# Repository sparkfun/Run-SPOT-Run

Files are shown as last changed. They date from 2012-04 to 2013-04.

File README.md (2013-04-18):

SatUpLink Shield
================
[SatUpLink Shield  
*SatUpLink Shield(DEV-11088)*](https://www.sparkfun.com/products/11088)

Run SPOT Run is a breakout board for the SPOT Connect version of the SPOT Geolocator. It is now retired on the SparkFun store front.

You will need your own registered SPOT ($150 for the hardware, $100 for the subscription), but after that, you should be able to broadcast small text messages (up to 40 characters) from most land masses on the globe.

Please see this [tutorial](http://www.sparkfun.com/tutorials/340) for more information. 

The hardware files were designed in Eagle v6.1.0 , and the firmware was developed in Arduino v1.0.

Repository Contents
-------------------
* **/Firmware** - Example Arduino sketch for running the shield 
* **/Hardware** - All Eagle design files (.brd, .sch)

License Information
-------------------
The hardware is released under [Creative Commons Share-alike 3.0](http://creativecommons.org/licenses/by-sa/3.0/).  
All other code is open source so please feel free to do anything you want with it; you buy me a beer if you use this and we meet someday ([Beerware license](http://en.wikipedia.org/wiki/Beerware)).

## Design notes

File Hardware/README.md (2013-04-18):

# What Are these Files?

The .sch and .brd files hare are Eagle CAD schematic and PCB design files.

These files were created with Eagle 6.1.0, you'll need Eagle 6.0 or later to open them up. There is a free, lite, version of Eagle available from [cadsoftusa.com](cadsoftusa.com).

# License

This product is open source! These Eagle files are released under the Creative Commons Share-Alike Attribution license ([CC BY-SA 3.0](http://creativecommons.org/licenses/by-sa/3.0/us/)).

Please use, reuse, and modify these files as you see fit. Please maintain attribution and release anything derivative under the same license.

- Your friends at SparkFun.

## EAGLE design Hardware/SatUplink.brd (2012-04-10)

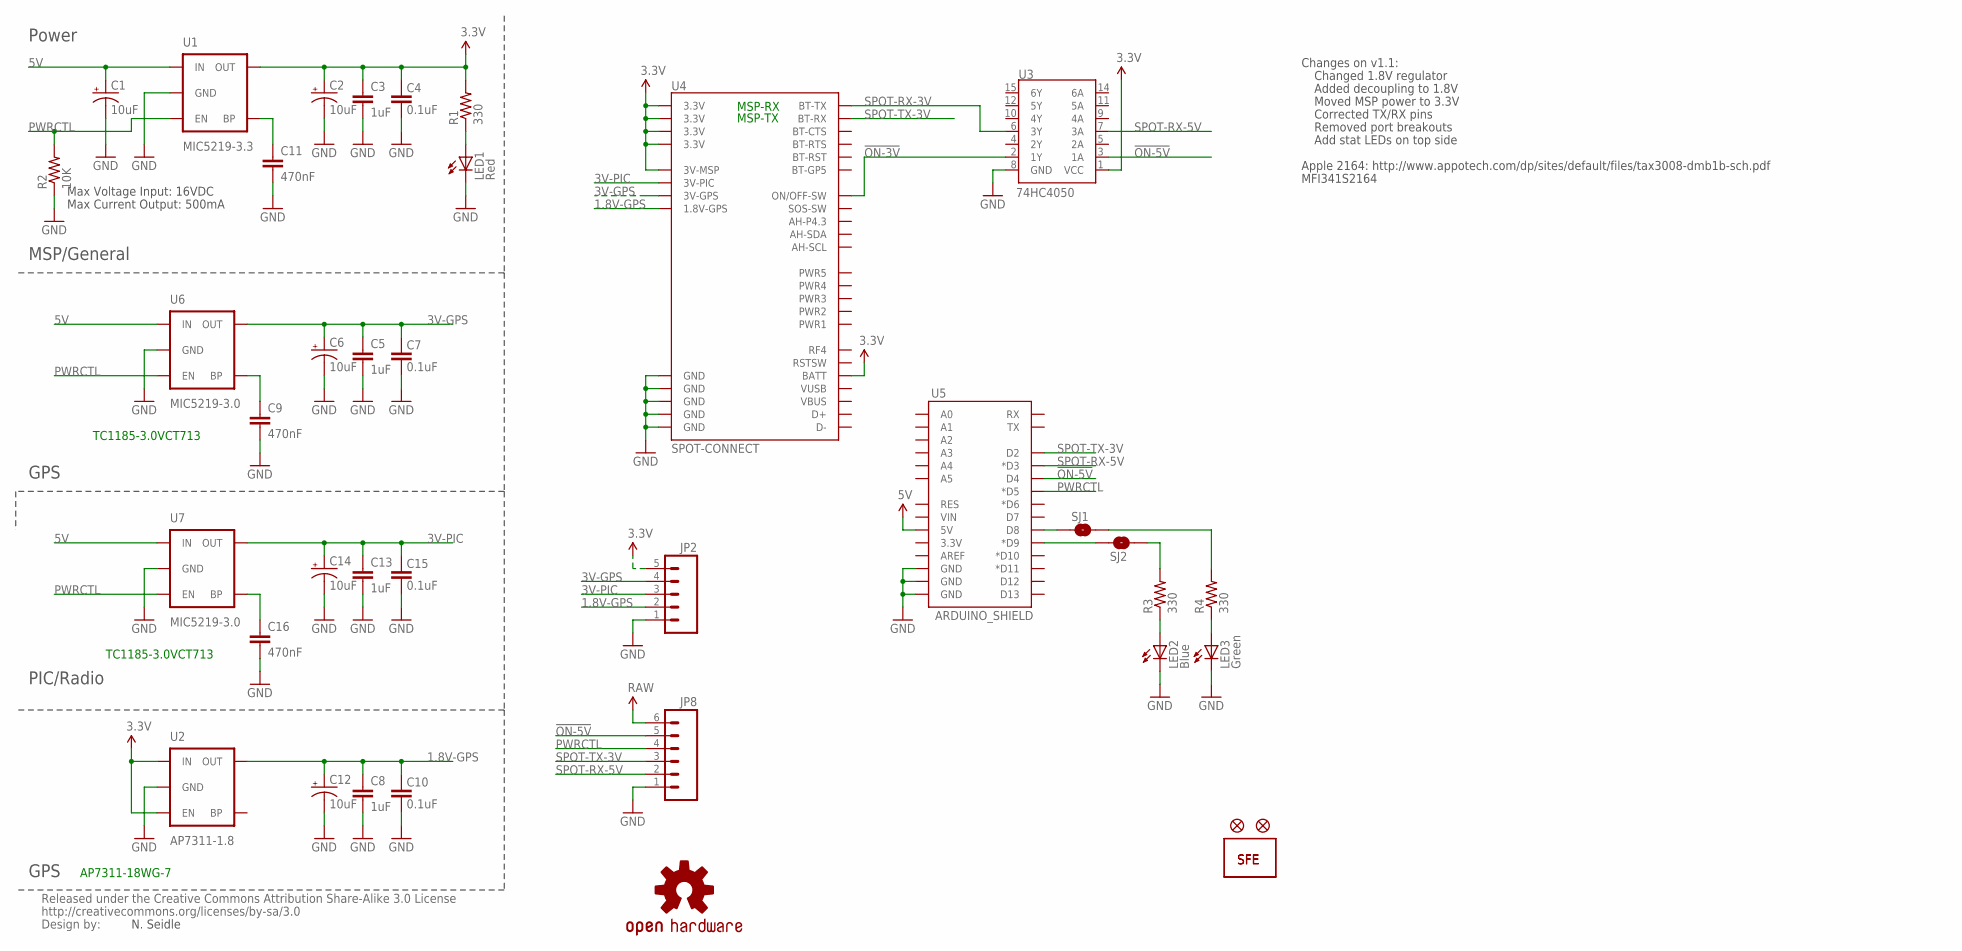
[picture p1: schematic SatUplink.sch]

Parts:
C1, C2, C6, C12, C14: 10uF; EIA3216
C3, C5, C8, C13: 1uF; 0402-CAP
C4, C7, C10, C15: 0.1uF; 0402-CAP
C9, C11, C16: 470nF; 0402-CAP
JP2: M05PTH; 1X05
JP8: M06SIP; 1X06
JP10, JP11: FIDUCIALUFIDUCIAL; MICRO-FIDUCIAL
LED1: Red; LED-0603
LED2: Blue; LED-0603
LED3: Green; LED-0603
R1, R3, R4: 330; 0402-RES
R2: 10K; 0402-RES
SJ1, SJ2: SOLDERJUMPERTRACE; SJ_2S-TRACE
U1: MIC5219-3.3; SOT23-5
U2: AP7311-1.8; SOT23-5
U3: 74HC4050; SO016
U4: SPOT-CONNECT
U5: ARDUINO_SHIELD; DUEMILANOVE_VIAS
U6, U7: MIC5219-3.0; SOT23-5
U$1: LOGO-SFESK; SFE-LOGO-FLAME
U$2: CREATIVE_COMMONS
U$3: OSHW-LOGOS; OSHW-LOGO-S
U$11: LOGO-SFENEW; SFE-NEW-WEBLOGO

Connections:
1.8V-GPS: C8.1, C10.2, C12.A (+), JP2.2, U2.5 (OUT), U4.1.8V-GPS
3.3V: C2.A (+), C3.1, C4.2, JP2.5, R1.2, U1.5 (OUT), U2.1 (IN), U2.3 (EN), U3.1 (VCC), U4.3.3V@1 (3.3V), U4.3.3V@2 (3.3V), U4.3.3V@3 (3.3V), U4.3.3V@4 (3.3V), U4.3VMSP (3V-MSP), U4.BATT
3V-GPS: C5.1, C6.A (+), C7.2, JP2.4, U4.3V-GPS, U6.5 (OUT)
3V-PIC: C13.1, C14.A (+), C15.2, JP2.3, U4.3VPIC (3V-PIC), U7.5 (OUT)
5V: C1.A (+), JP8.6, U1.1 (IN), U5.5V, U6.1 (IN), U7.1 (IN)
!ON-3V: U3.2 (1Y), U4.ON/OFF (ON/OFF-SW)
!ON-5V: JP8.5, U3.3 (1A), U5.D4
GND: C1.C (-), C2.C (-), C3.2, C4.1, C5.2, C6.C (-), C7.1, C8.2, C9.2, C10.1, C11.2, C12.C (-), C13.2, C14.C (-), C15.1, C16.2, JP2.1, JP8.1, LED1.C, LED2.C, LED3.C, R2.1, U1.2 (GND), U2.2 (GND), U3.8 (GND), U4.GND@1 (GND), U4.GND@2 (GND), U4.GND@3 (GND), U4.GND@4 (GND), U4.GND@5 (GND), U5.GND@0 (GND), U5.GND@1 (GND), U5.GND@2 (GND), U6.2 (GND), U7.2 (GND)
unnamed: C16.1, U7.4 (BP)
unnamed: R4.2, SJ1.2
unnamed: R3.2, SJ2.2
unnamed: C9.1, U6.4 (BP)
unnamed: LED2.A, R3.1
unnamed: LED3.A, R4.1
unnamed: SJ1.1, U5.D8
unnamed: SJ2.1, U5.D9 (*D9)
unnamed: C11.1, U1.4 (BP)
unnamed: LED1.A, R1.1
PWRCTL: JP8.4, R2.2, U1.3 (EN), U5.D5 (*D5), U6.3 (EN), U7.3 (EN)
SPOT-RX-3V: U3.6 (3Y), U4.BT-TX
SPOT-RX-5V: JP8.2, U3.7 (3A), U5.D3 (*D3)
SPOT-TX-3V: JP8.3, U4.BT-RX, U5.D2

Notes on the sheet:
Max Voltage Input: 16VDC
Max Current Output: 500mA
N. Seidle
TC1185-3.0VCT713
Add stat LEDs on top side
Apple 2164: http://www.appotech.com/dp/sites/default/files/tax3008-dmb1b-sch.pdf
MFI341S2164
MSP-TX
MSP-RX
AP7311-18WG-7
Changes on v1.1:
Added decoupling to 1.8V
Changed 1.8V regulator
Moved MSP power to 3.3V
Corrected TX/RX pins
Removed port breakouts
PIC/Radio
GPS
MSP/General
Power

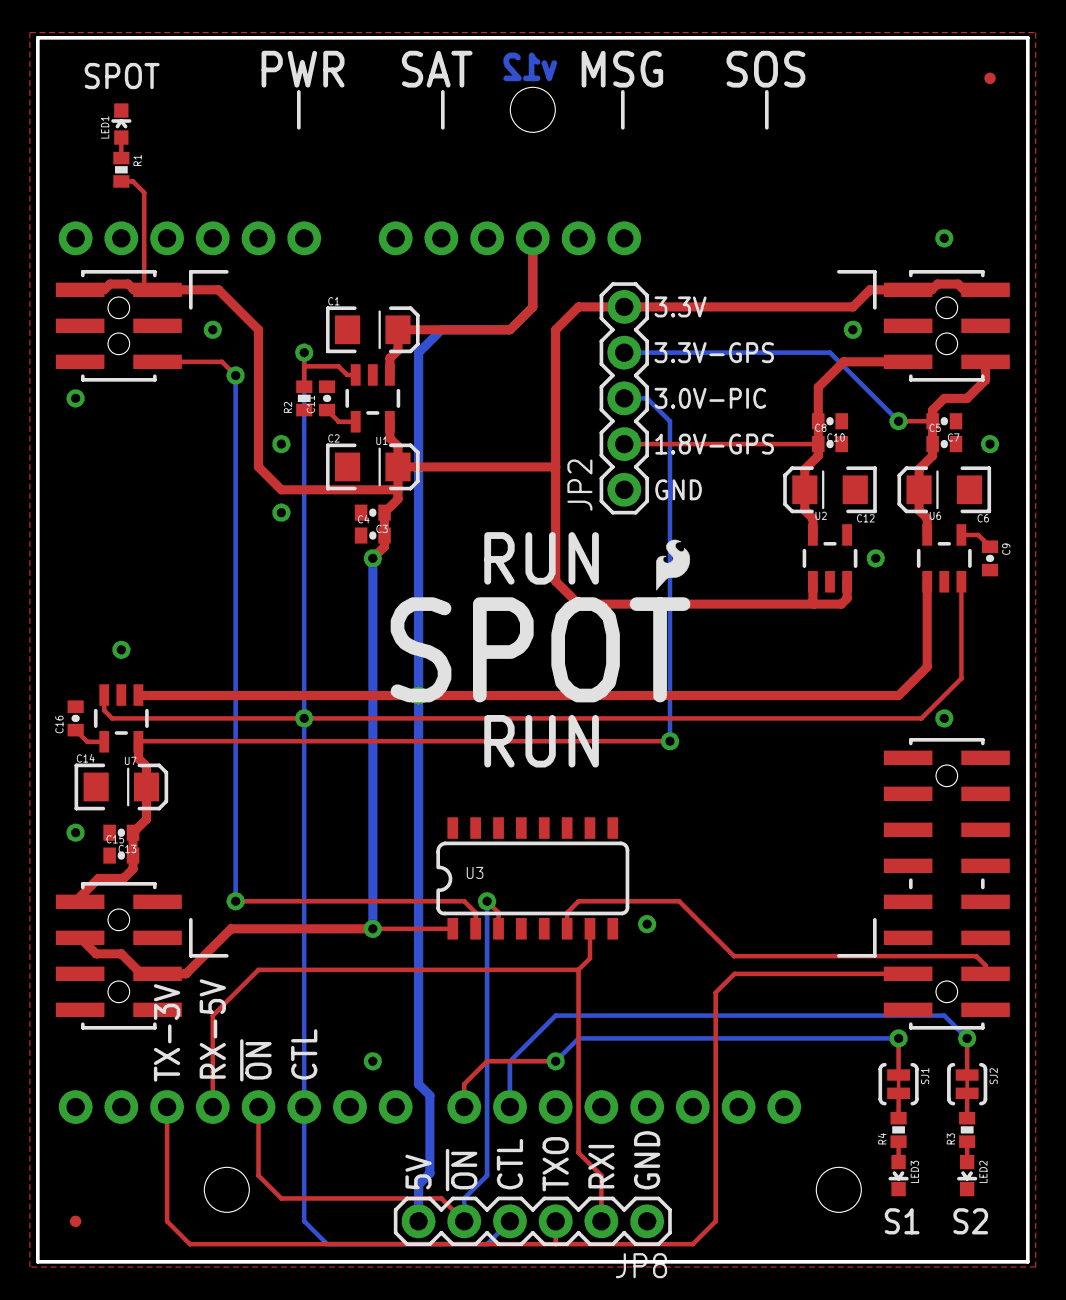
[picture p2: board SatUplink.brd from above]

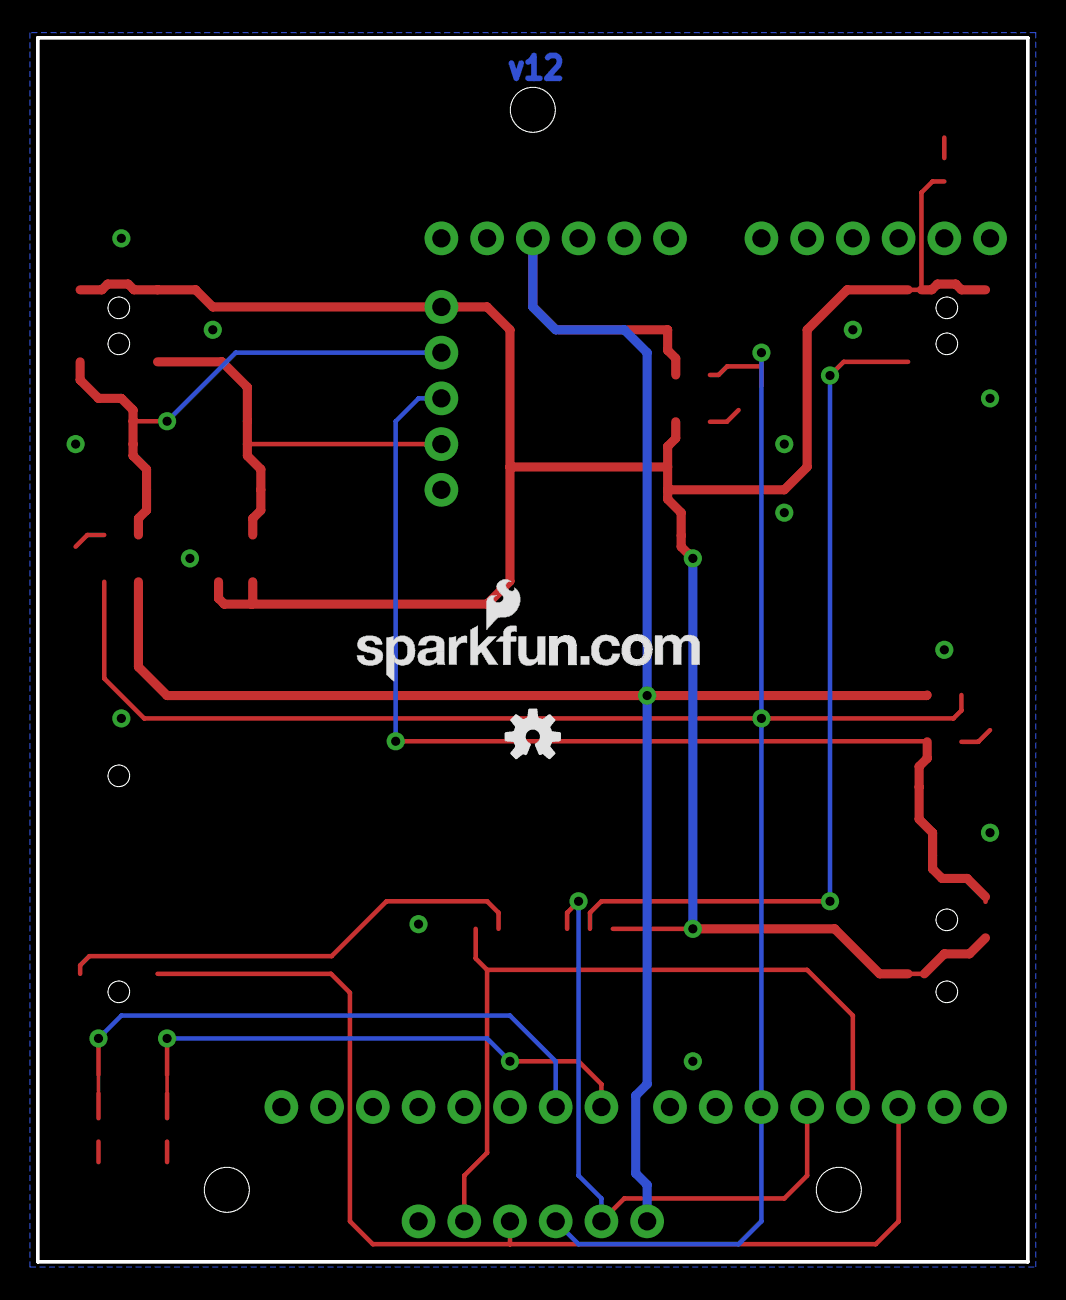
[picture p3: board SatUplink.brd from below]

Board: 2 copper layers, 55.0 x 68.0 mm, 40 parts (2 on the bottom side), 22 nets.

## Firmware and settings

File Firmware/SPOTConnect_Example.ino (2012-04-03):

/*
 12-22-2011
 Spark Fun Electronics 2012
 Nathan Seidle
 
 This code is public domain but you buy me a beer if you use this and we meet someday (Beerware license).
 
 This example code tells the SPOT to transmit the message "Hello Stars" and then check the unit's status registers.
 
 For more information, see the SparkFun tutorial: http://www.sparkfun.com/tutorials/340
 
 Log into the SPOT website and setup your SPOT to send text messages or emails to a known good recipient (I recommend
 your cell phone and your email). Remember to use an activated SPOT, outdoors with a clear view of the sky. 
 
 Connect the following pins
 SPOT TXO : Arduino 2
 SPOT RXI : Arduino 3
 SPOT CTL : Arduino 5
 SPOT ON* : Arduino 4

 Note: SoftwareSerial cannot handle incoming 115200bps so we had to bit-bang incoming bytes using getbyte_115200(). 
 SoftwareSerial opens pin 7 as the RX pin but we do not use it. Instead, the getbyte_115200 receives bytes on pin 3.
 getbyte_115200 is configured to work at 16Mz.
 */

#include <SoftwareSerial.h>

//All the following are variables needed to use SPOT
//-=-=-=-=-=-=-=-=-=-=-=-=-=-=-=-=-=-=-=-=-=-=-=-=-=-=-=-=-=-=-=-=-=-


int SPOTrx = 2; //Receive from SPOT (TXO pin on breakout) into pin 2 on Arduino
int SPOTtx = 3; //Transmit out to SPOT (RXI pin on breakout) from pin 3 on breakout
//SoftwareSerial(rxPin, txPin)
SoftwareSerial softSPOT(7, SPOTtx); //Dummy soft RX on 7 (not actually used), Soft TX out on SPOTtx

int onButton = 4; //Holding this pin low for more than 5 seconds will power up SPOT in Bluetooth discovery mode
int powerControl = 5; //This controls the voltage regulators on the SPOT breakout board, active high

int numberOfPowerOns = 0;
int unitStatus = 0; //0x00 = GPS/Radio powered off, 0x07 = GPS searching, 0x0F = GPS lock, 0x06 = transmitting to satellite network
int timeToNextCheckin = 0; //Starts at 0. In seconds Once GPS locks, will increase to a large number then count down to next try.
int sentTries = 0; //Starts at 0 and goes to 1, then to 2, then unit shuts down.
int gpsStatus = 0; //Goes to 0x01 once we have good GPS coords. GPS will then be powered down.
int satsInView = 0;

unsigned char SPOT_requestUnitID[] = { 
  0xAA, 0x03, 0x01 };

unsigned char SPOT_requestStatus[] = { 
  0xAA, 0x03, 0x52 };

unsigned char SPOT_requestLastGPS[] = { 
  0xAA, 0x03, 0x25 };

char buffer[200]; //Used for status sprintf things

int messageNumber = 1; //Let's add a # variable to the message we send out
//-=-=-=-=-=-=-=-=-=-=-=-=-=-=-=-=-=-=-=-=-=-=-=-=-=-=-=-=-=-=-=-=-=-

int statusLED = 13; //Arduino default stat LED

void setup() {
  Serial.begin(115200);

  pinMode(statusLED, OUTPUT);
  digitalWrite(statusLED, HIGH);

  int tries;
  for(tries = 0 ; tries < 3 ; tries++){

    SPOTsetup(); //Init the IO pins for the SPOT
    SPOTcheckStatus(); //Check for a valid response

    if(unitStatus != 255) break; //255 = SPOT didn't respond

    Serial.print("SPOT failed to respond.");
  }

  if(tries == 3) { //Give up!
    Serial.print("Please check connections.");
    
    while(1){ //Infini-blink error
      digitalWrite(8, HIGH);
      delay(1000);
      digitalWrite(8, LOW);
      delay(1000);
    }
  }
  
}

void loop() {
  
  if(SPOTcheckStatus()) {

    Serial.print("[Unit Status:");
    if(unitStatus == 0) Serial.print("Waiting Cmd]");
    else if(unitStatus == 0x07) Serial.print("GPS Search]");
    else if(unitStatus == 0x0F) Serial.print("GPS Lock]");
    else if(unitStatus == 0x06) Serial.print("Xmit to Sats]");
    else Serial.print("No response]");

    if(gpsStatus == 0) Serial.print(" (No location)");
    else if(gpsStatus == 1) Serial.print(" (Location good)");

    sprintf(buffer, " [Sats:%02d] [Next Xmit:%02d] [Try#:%02d] [#ofPowerOns:%02d]", satsInView, timeToNextCheckin, sentTries, numberOfPowerOns);
    Serial.println(buffer);

  }
  else {
    Serial.println("SPOT failed to respond to status check");
    unitStatus = 0xFF; //Error mode
  }

  //Let's send a new message!
  if(unitStatus == 0) {
    String msgToSend = "Hello Stars! Msg#:" + String(messageNumber); //This is the message to send
    //String msgToSend = "Test"; //For testing

    int msgLength = 8 + msgToSend.length(); //There are 8 data bytes before the message begins 
    
    byte SPOTmsg[100];
    
    SPOTmsg[0] = 0xAA; //Preamble
    SPOTmsg[1] = msgLength; //Frame length
    SPOTmsg[2] = 0x26; //Transmit
    SPOTmsg[3] = 0x01; //0x01 = I'm ok, 0x04 = Help, 0x40 = Track?)
    SPOTmsg[4] = 0x00; //Unknown
    SPOTmsg[5] = 0x01; //Unknown
    SPOTmsg[6] = 0x00; //Unknown
    SPOTmsg[7] = 0x01; //Unknown
    for(int x = 0 ; x < msgToSend.length() ; x++)
      SPOTmsg[8 + x] = msgToSend[x]; //Attach message onto frame
      
    //Serial.print("Message:");
    for(int i = 0 ; i < msgLength ; i++) {
      softSPOT.print(char(SPOTmsg[i])); //Push message request

      //sprintf(buffer, "%02X ", SPOTmsg[i]);
      //Serial.print(buffer);
    }
    //Serial.println();

    Serial.println("Message sent");
    
    messageNumber++; //Advance to the next message number
  }

  delay(1000); //Check status every second
}

//Sets up the IO pins for the SPOT
//We also power cycle the unit and then put the unit into
//Bluetooth discovery mode. After this runs, you should see the blue LED blinking on the SPOT
void SPOTsetup(void) {
  softSPOT.begin(115200); //Setup software TX on pin 3

  digitalWrite(onButton, HIGH);
  pinMode(onButton, OUTPUT);
  
  pinMode(SPOTrx, INPUT);
  digitalWrite(SPOTrx, HIGH);

  //This will power cycle the SPOT
  //Because we want the unit in a known reset state, I don't recommend shortening
  //the power off or on time without lots of testing with your own application
  Serial.println("Regulators off");
  digitalWrite(powerControl, LOW); //Turn off voltage regulators
  pinMode(powerControl, OUTPUT);
  delay(500);
  digitalWrite(powerControl, HIGH); //Turn on voltage regulators
  delay(500);
  Serial.println("Regulators on");

  //Next we hold the On button of the SPOT for 4 seconds
  Serial.println("Turning SPOT on");
  digitalWrite(onButton, LOW);
  //delay(3000); //Normal mode - won't work with this code
  delay(4000); //Bluetooth discovery mode

//  digitalWrite(onButton, HIGH);
  pinMode(onButton, INPUT); //Release on button

  delay(3500); //Wait for the main processor (MSP) to come online
  Serial.println("SPOT is now on");
}

//Check Status of the SPOT unit. This will load the global variables with the latest values for
//unit status, number of power ons, sent tries, sats in view, and time to checkin.
//You can check the status every 5 to 10ms, but normal is 1 to 10 seconds.
int SPOTcheckStatus(void) {
  byte SPOTresponse[50];
  
  //Send request to SPOT
  for(int i = 0 ; i < 3 ; i++)
    softSPOT.print(char(SPOT_requestStatus[i])); //Push message request at 115200bps
  
  cli();
  for(int x = 0 ; x < 32 ; x++) 
    SPOTresponse[x] = getByte_115200();
  sei();

  //For debugging
  Serial.print("Status Array: ");
  for(int x = 0 ; x < 32 ; x++) {
    sprintf(buffer, "%02X ", (byte)SPOTresponse[x]);
    Serial.print(buffer);
  }
  Serial.println();

  if(SPOTresponse[0] == 0xAA) { //We have found the header!

    numberOfPowerOns = SPOTresponse[6];

    unitStatus = SPOTresponse[7]; //0x00 = GPS/Radio powered off, 0x07 = GPS searching, 0x0F = GPS lock, 0x06 = transmitting to satellite network

    timeToNextCheckin = (SPOTresponse[11] << 8) | SPOTresponse[12];

    sentTries = SPOTresponse[19]; //Starts at 0 and goes to 1, then to 2, then unit shuts down.

    gpsStatus = SPOTresponse[26]; //Goes to 0x01 once we have good GPS coords. GPS will then be powered down.

    satsInView = SPOTresponse[31];
    
    return(1); //We got a good response
  }
  else {
    numberOfPowerOns = 0;

    unitStatus = 255; //0x00 = GPS/Radio powered off, 0x07 = GPS searching, 0x0F = GPS lock, 0x06 = transmitting to satellite network

    timeToNextCheckin = 0;

    sentTries = 0; //Starts at 0 and goes to 1, then to 2, then unit shuts down.

    gpsStatus = 0; //Goes to 0x01 once we have good GPS coords. GPS will then be powered down.

    satsInView = 0;

    return(0); //We didn't get a response in time!
  }
}

//This function receives characters at 115200bps
//SoftwareSerial doesn't support full bandwidth 115200 so we have to bit-bang it
//This code only works at 16MHz. Use a logic analyzer to eval the timing (cut the cycles in half) if 
//you need to work at 8MHz.
//Modifying any part of this code will throw the timing off.
byte getByte_115200() {

  pinMode(8, OUTPUT); //Used to toggle a pin for time measurements

  int timeOut = 0;
  while((PIND & 1<<2)){
    delayMicroseconds(1); //Wait for the start of a new byte
    if(timeOut++ > 10000) return(0);
  }

  delay_us(2);

  byte myByte = 0;
  for(char x = 0 ; x < 8 ; x++) {
    delay_us(3); //On the first loop, this will wait for the middle of bit 1

    myByte >>= 1;

    PORTB &= ~(1<<0); //To measure timing on Pin8
    if(PIND & 1<<2) //SPOTrx on 2 is PD2 on the ATmega
      myByte |= 0b10000000;
    else
      myByte |= 0; //This is here for definitive number of cycles
  
    PORTB |= (1<<0); //To measure timing on Pin8
  }

  return myByte;
}

//This delay routine only works at 16MHz
//This has been carefully trimmed 
void delay_us(char x) {
  while(x--) {
    __asm__("nop\n\t");
    __asm__("nop\n\t");
    __asm__("nop\n\t");
    __asm__("nop\n\t");
    __asm__("nop\n\t");
    __asm__("nop\n\t");
    __asm__("nop\n\t");
    __asm__("nop\n\t");
    __asm__("nop\n\t");
    __asm__("nop\n\t");
    __asm__("nop\n\t");
    __asm__("nop\n\t");
    __asm__("nop\n\t");
    __asm__("nop\n\t");
    __asm__("nop\n\t");
    __asm__("nop\n\t");
    __asm__("nop\n\t");
    __asm__("nop\n\t");
    __asm__("nop\n\t");
    __asm__("nop\n\t");
    __asm__("nop\n\t");
    __asm__("nop\n\t");
    __asm__("nop\n\t");
    __asm__("nop\n\t");
    __asm__("nop\n\t");
    __asm__("nop\n\t");
    __asm__("nop\n\t");
    __asm__("nop\n\t");
    __asm__("nop\n\t");
    __asm__("nop\n\t");
    __asm__("nop\n\t");
    __asm__("nop\n\t");
  }
}

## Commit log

2012-04-03 Original commit.
    [SatUplink-v10.brd, SatUplink-v10.sch, SatUplink-v11.brd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]
2012-04-10 Fixing schematic typo.
    [SatUplink-v12.sch]
2013-04-18 Fix repo structure, add .git files, update README
    [SatUplink-v10.brd, SatUplink-v10.sch, SatUplink-v11.brd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]

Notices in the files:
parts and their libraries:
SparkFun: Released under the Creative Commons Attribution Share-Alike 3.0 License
